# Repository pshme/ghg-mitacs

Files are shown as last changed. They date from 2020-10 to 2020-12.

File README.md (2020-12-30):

# **GHG Sensing Project**

## **Introduction and Overview**

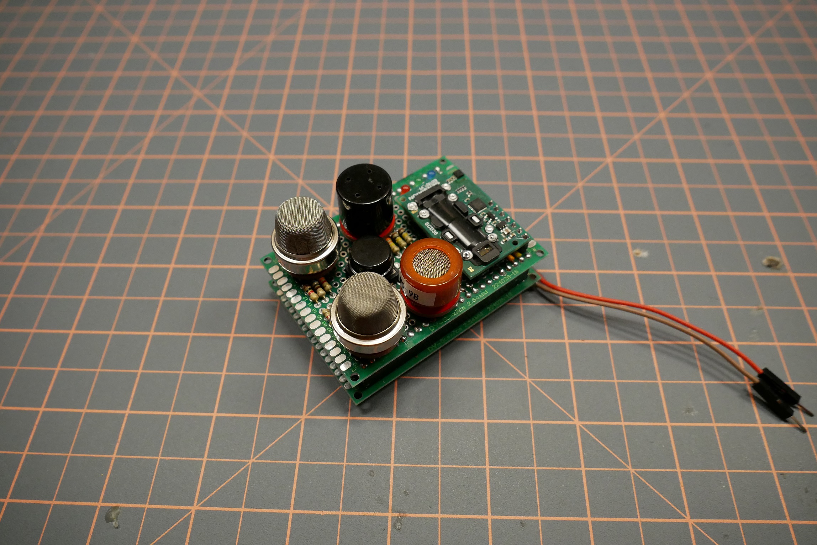
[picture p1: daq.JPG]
DAQ prototype


The purpose of this research project was to find low-cost and low-power sensors and integrate them into a compact DAQ (Data Acquisition) system for use in UAVs (Unmanned Aerial Vehicles). The sensors measure GHGs (Greenhouse Gasses) in the atmosphere along with complementary ambient readings such as temperature, humidity, and pressure.

The prototype DAQ system uses the following components:

* PJRC Teensy 4.1 Arduino-based microcontroller
* Pololu 5V 2.5A Step-Down Regulator (D24V22F5)
* Pololu 3.3V Step-Up/Step-Down Regulator (S7V8F3)
* Sensirion SCD30 CO2, humidity, and temperature sensor
* Winsen MQ-4 CH4 Sensor
* Winsen MQ-9B CO and CH4 Sensor
* Winsen MQ-131 O3 Sensor
* Winsen MQ-137 NH3 Sensor
* SparkFun Barometric Pressure Sensor (MPL115A1)
* SparkFun Gas Sensor Breakout Boards
* Toggle button, LEDs, and resistors.

Each Winsen sensor was individually calibrated to determine the sensor's resistance and also convert the 5V to 3.3V output logic. The Sensirion SCD30 was calibrated by leaving the sensor powered on in an outdoor environment for 1 hour every day. The DAQ records data to the SD card every 2 seconds.

## **Basic Operation**

### **Hardware Controls**

The DAQ has 3 LEDs (one red, one green, and one blue) which represent the state of the system. There are **three** main states and **one** exception state. There is also a button which allows you to either start or end loggint to the SD card. When the DAQ is first powered on, the system is not logging any data and the red LED is *solid*. When the button is pressed, then the system can enter one of the following states: 

* *SOLID* **GREEN**, *FLASHING* **BLUE** - system is logging to SD card every 2 seconds
* *Flashing* **RED, GREEN, BLUE** - error with SD card or SD card not inserted (reboot to resolve)
* *SOLID* **RED, GREEN**, *FLASHING* **BLUE** - O3 sensor not recording data, but other sensors are (exceptions state)

To exit out of one of the four states, the button must be pressed again; however, if there is an error with the SD card or the SD card is not inserted, then you must reboot the DAQ and check that the error is resolved. 

### **Matlab Plotting**

The Arduino code (*main_ghg_code.ino*) has been modified to first display a title for each column in the .txt file. This helps simplify the Matlab import process. Once a test has been logged to the SD card, the **Import Data** function can be used. It is important to make sure that the information is *delimited* by commas and that each column is imported to Workspace as a **column vector**. After importing the section, *daq_import.m* can be ran, and the graphs will be produced. The graphs display the gas concentration, temperature, pressure, or humidity with respect to time which is converted from 2 second intervals to hours:minutes:seconds to make the graph more legible.

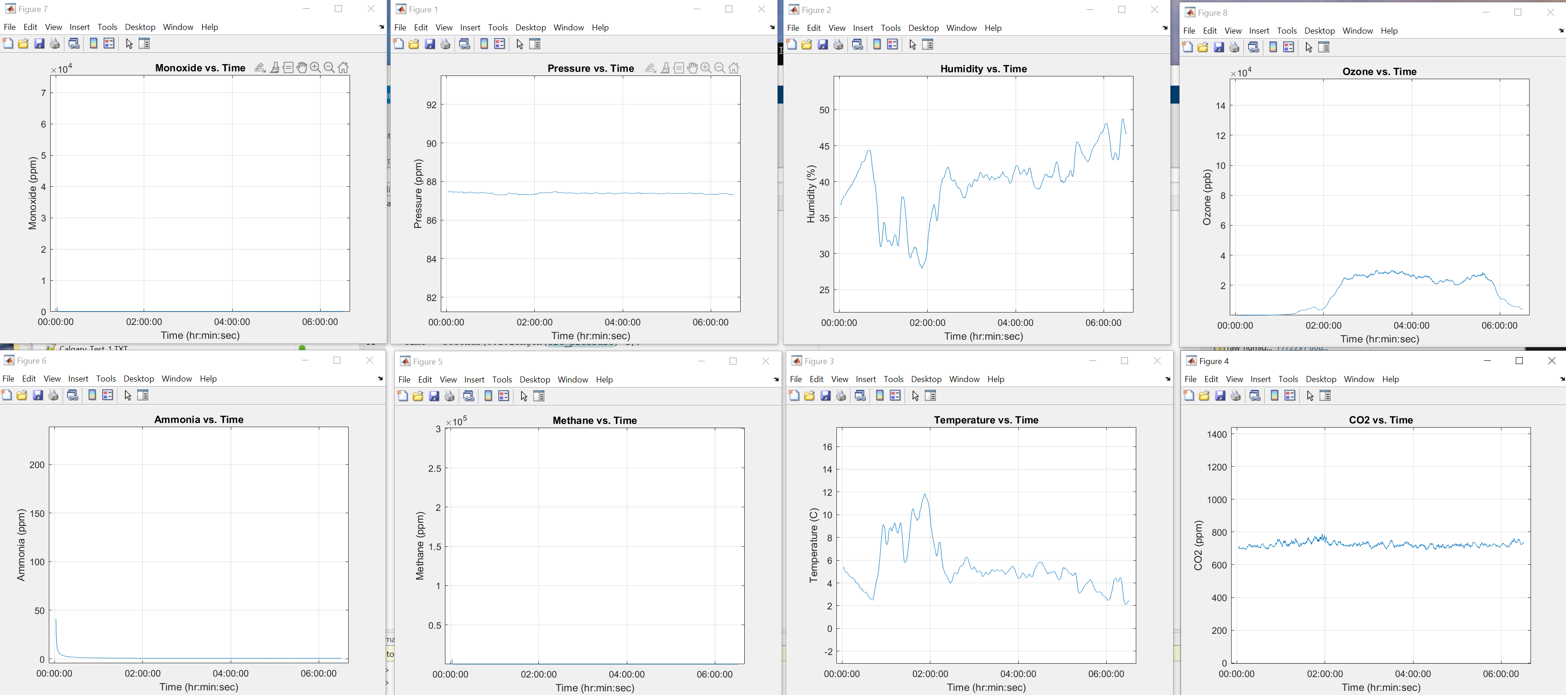
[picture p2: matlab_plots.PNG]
Matlab plots


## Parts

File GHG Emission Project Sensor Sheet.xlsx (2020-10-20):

Manufacturer |  | Gas | Sensor ID | Sensor Type |  | Weight (g) | Dimensions (LxWxHmm) |  | Measurement Accuracy (ppm) |  | Measurement Range (ppm) |  | Measurement Rate (sec/mes.) |  | Voltage Input (VDC) | Peak Current (mA) | Operating Temperature (°C) | Communication Protocol | Price (CAD) | Link
CozIR |  | CO2 | GC-0012 | NDIR |  | 20 | N/A |  | ± 50 ppm ± 3% |  | 0 - 10000 |  | 0.5 |  | 3.3 - 5.5 | 33 | 0 - 50 | UART | $142.70 | https://www.co2meter.com/products/cozir-ambient-10000-ppm-co2-sensor?variant=840094613524
SenseAir |  | CO2 | SE-0018 K30 | NDIR |  | N/A | 51 × 57 × 14 |  | ± 30 ppm ± 3 % |  | 0 - 10000 |  | 2 |  | 5.5 - 14 | 150 | 0 - 50 | UART/I2C | $111.28 | https://www.co2meter.com/products/k-30-co2-sensor-module
SenseAir |  | CO2 | SE-0119 S8 | NDIR |  | 8 | 32.7 × 19.7 × 8 |  | ± 70ppm ± 3% |  | 0 - 10000 |  | 2 |  | 4.5 - 5.25 | 300 | 0 - 50 | UART/Modbus | $111.28 | https://www.co2meter.com/products/s8-miniature-co2-sensor-1
SenseAir |  | CO2 | SE-0038 LP8 | NDIR |  | 8 | 32.7 × 19.7 × 8 |  | ± 50ppm ± 3% |  | 0 - 10000 |  | >15 |  | 2.9 - 5.5 | 125 | 0 - 50 | UART | $155.79 | https://www.co2meter.com/products/lp8-miniature-co2-sensor
CozIR |  | CO2 | GC-0027 | NDIR |  | 5 | 31 x 19.5 x 8 |  | ± 50ppm ± 3% |  | 0 - 5000 |  | <30 |  | 3.25 - 5.5 | 33 | 0 - 50 | UART | $142.70 | https://www.co2meter.com/products/cozir-lp-ambient-air-co2-sensor?variant=40754444884
SprintIR |  | CO2 | GC-0028 | NDIR |  | 16 | 25 x 40 x 31 |  | ± 70ppm ± 5% |  | 0 - 50000 |  | 2 |  | 3.25 - 5.5 | 33 | 0 - 50 | UART | $325.98 | https://www.co2meter.com/products/sprintir6s-5-co2-smart-sensor
SenseAir |  | CO2 | SE-11 | NDIR |  | 4.9 | 33 x 19.8 x 11.9 |  | ± 30ppm ± 3% |  | 400 - 10000 |  | 2 |  | 3.05 - 5.5 | 125 | 0 - 50 | UART/I2C | $82.46 | https://www.digikey.ca/en/products/detail/senseair-north-america-inc/006-0-0002/10416535
Sensirion |  | CO2 | SCD30 | NDIR |  | 3.4 | 35 x 23 x 7.00 |  | ± 30ppm ± 3% |  | 400 - 10000 |  | 2 |  | 3.3 - 5.5 | 75 | 0 - 50 | UART/I2C | $81.78 | https://www.digikey.ca/en/products/detail/sensirion-ag/SCD30/8445334
Fiargo |  | CO2 | FG-010 | NDIR |  | 3 | 32 x 17 x 7.4 |  | ± 50ppm ± 3% |  | 300 - 5000 |  | 2 |  | 4.75 - 5.25 | 60 | 0 - 50 | UART/I2C/PWM | $155.79 | https://www.co2meter.com/collections/0-1-co2/products/figaro-5000ppm-co2-sensor
NCD |  | CH4 | MQ-4 | MOS |  | N/A | N/A |  | N/A |  | 200 - 10000 |  | N/A |  | 5 | N/A | -10 - 50 | I2C | $39.32 | https://store.ncd.io/product/mq-4-methane-natural-gas-sensor-adc121c-12-bit-adc-i2c-mini-module/
NCD |  | CO | MQ-7 | MOS |  | N/A | N/A |  | N/A |  | 20 - 2000 |  | N/A |  | 5 | N/A | -20 - 50 | I2C | $39.32 | https://store.ncd.io/product/mq-7-carbon-monoxide-gas-sensor-adc121c-12-bit-adc-i2c-mini-module/
DF Robot |  | O3 | SEN0321 | EC |  | 22 | 37 x 27 |  | N/A |  | 0 - 10 |  | <90 |  | 3.3 - 5 | N/A | -20 - 50 | I2C | $70.56 | https://www.mouser.ca/ProductDetail/DFRobot/SEN0321?qs=GedFDFLaBXFKYEA7aR%2FFOA%3D%3D
NCD |  | O3 | MQ131 | MOS |  | N/A | N/A |  | N/A |  | 10 - 1000 |  | N/A |  | 5 | N/A | N/A | I2C | $56.29 | https://store.ncd.io/product/mq131-ozone-gas-sensor-adc121c-12-bit-adc-i%c2%b2c-mini-module/
Euro Gasman |  | All | 4 Series MS | EC |  | N/A | 23 x 22 x 24.5 |  | N/A |  | N/A |  | N/A |  | 3.3 - 5 | N/A | N/A | I2C | N/A | https://euro-gasman.com/product/4-8v-digital-i2cbus-transmitter/
SpecSensors |  | CO | DGS-CO 968-034 | EC |  | 20 | 44.5 x 20.8 x 8.9 |  | ± 15% |  | 0 - 1000 |  | 5 |  | 2.6 - 3.6 | 4 | -30 - 50 | UART | 113.59 | https://www.digikey.ca/en/products/detail/spec-sensors-llc/968-034/6676880
SpecSensors |  | O3 | DGS-O3968-042 | EC |  | 20 | 44.5 x 20.8 x 8.9 |  | ± 15% |  | 0 - 5 |  | 1 |  | 3.0 - 3.6 | 4.3 | -30 - 50 | UART | 113.59 | https://www.digikey.ca/en/products/detail/spec-sensors-llc/968-042/7689227
SpecSensors |  | NO2 | DGS-NO2968-043 | EC |  | 20 | 44.5 x 20.8 x 8.9 |  | ± 15% |  | 0 - 5 |  | 1 |  | 3.0 - 3.6 | 4.3 | -30 - 50 | UART | 113.59 | https://www.digikey.ca/en/products/detail/spec-sensors-llc/968-043/7689228
Winsen |  | CO | MQ-7 | MOS |  | 10 | 30 x 20 x 20 |  | ± ~30% |  | 10 - 1000 |  | 1 |  | 5 | 250 | -20 - 50 | Analog | $7.99 | https://x2robotics.ca/mq-7-carbon-monoxide-gas-sensor?search=MQ
Winsen |  | CH4 | MQ-4 | MOS |  | 10 | 30 x 20 x 20 |  | ± ~30% |  | 300 - 10000 |  | 1 |  | 5 | 250 | -20 - 50 | Analog | $5.99 | https://x2robotics.ca/mq-4-methane-gas-sensor?search=MQ
Winsen |  | H2 | MQ-8 | MOS |  | 10 | 30 x 20 x 20 |  | ± ~30% |  | 100 - 1000 |  | 1 |  | 5 | 250 | -20 - 50 | Analog | $5.99 | https://x2robotics.ca/mq-8-hydrogen-gas-sensor?search=MQ
Mikroe |  | CO | MIKROE-3196 | EC |  | 20 | 57.2 x 25x4 x 10 |  | ± 15% |  | 0 - 1000 |  | 5 |  | 3.3 - 5 | ~50 | -30 - 50 | Analog/I2C | $68.99 | https://www.mikroe.com/co-2-click
Mikroe |  | NH3 | MIKROE-4151 | MOS |  | 20 | 57.15 x 25.4 x 10 |  | ± ~30% |  | 5 - 200 |  | 1 |  | 3.3 - 5 | 250 | -30 - 50 | Analog/SPI | $68.99 | https://www.mikroe.com/ammonia-click
Mikroe |  | O3 | MIKROE-2767 | MOS |  | 20 | 57.2 x 25x4 x 10 |  | ± ~30% |  | 10 - 1000 |  | 1 |  | 3.3 - 5 | 250 | -20 - 50 | Analog/SPI | $48.85 | https://www.mikroe.com/ozone-2-click
Mikroe |  | NO2 | MIKROE-3098 | MOS |  | 20 | 57.2 x 25x4 x 10 |  | ± 15% |  | 0 - 20 |  | 1 |  | 3.3 - 5 | ~50 | -30 - 50 | Analog/I2C | $68.99 | https://www.mikroe.com/no2-click
 | Agricultural Emissions |  |  | Abreviation |  |  | Manufacturer | Sensor Type |  | Protocol | Price (CAD) | Link |  | Total Current (mA)
 | CO2 |  | 400ppm+ | MOS | Semiconductor |  | Sparkfun | Accelerometer |  | I2C | $13.14 | https://www.sparkfun.com/products/12756 |  | 875
 | CH4 |  | 1.8 - 2ppm | EC | Electrochemical |  | Sparkfun | Temperature |  | I2C | $5.61 | https://www.sparkfun.com/products/13314 | .1 deg C
 | CO |  | 0 - 2ppm | CAT | Catalytic |  | Sparkfun | Alt/Pressure |  | I2C | $19.74 | https://www.sparkfun.com/products/11084 | good resolution
 | NH3 |  | 0 - 0.2ppb | NDIR | Infrared |  | Sparkfun | Humidity |  | I2C | $13.14 | https://www.sparkfun.com/products/16467 | 1%
 | NO2 |  | 0 - 160ppb
 | O3 |  | 0-3ppm
 | H2
 | NH4
 | NO |  |  |  |  |  | Typical Range table
 | N2O |  |  |  |  |  | environment |  |  | https://www.figarosensor.com/product/entry/tgs2600.html#ti
 |  |  |  |  |  |  | agricultural emmison
 |  |  |  |  |  |  | inlcude Teensy
 |  |  |  |  |  |  | breadboard
 |  |  |  |  |  |  | perfboard
 |  |  |  |  |  |  | solder
 |  |  |  |  |  |  | tools

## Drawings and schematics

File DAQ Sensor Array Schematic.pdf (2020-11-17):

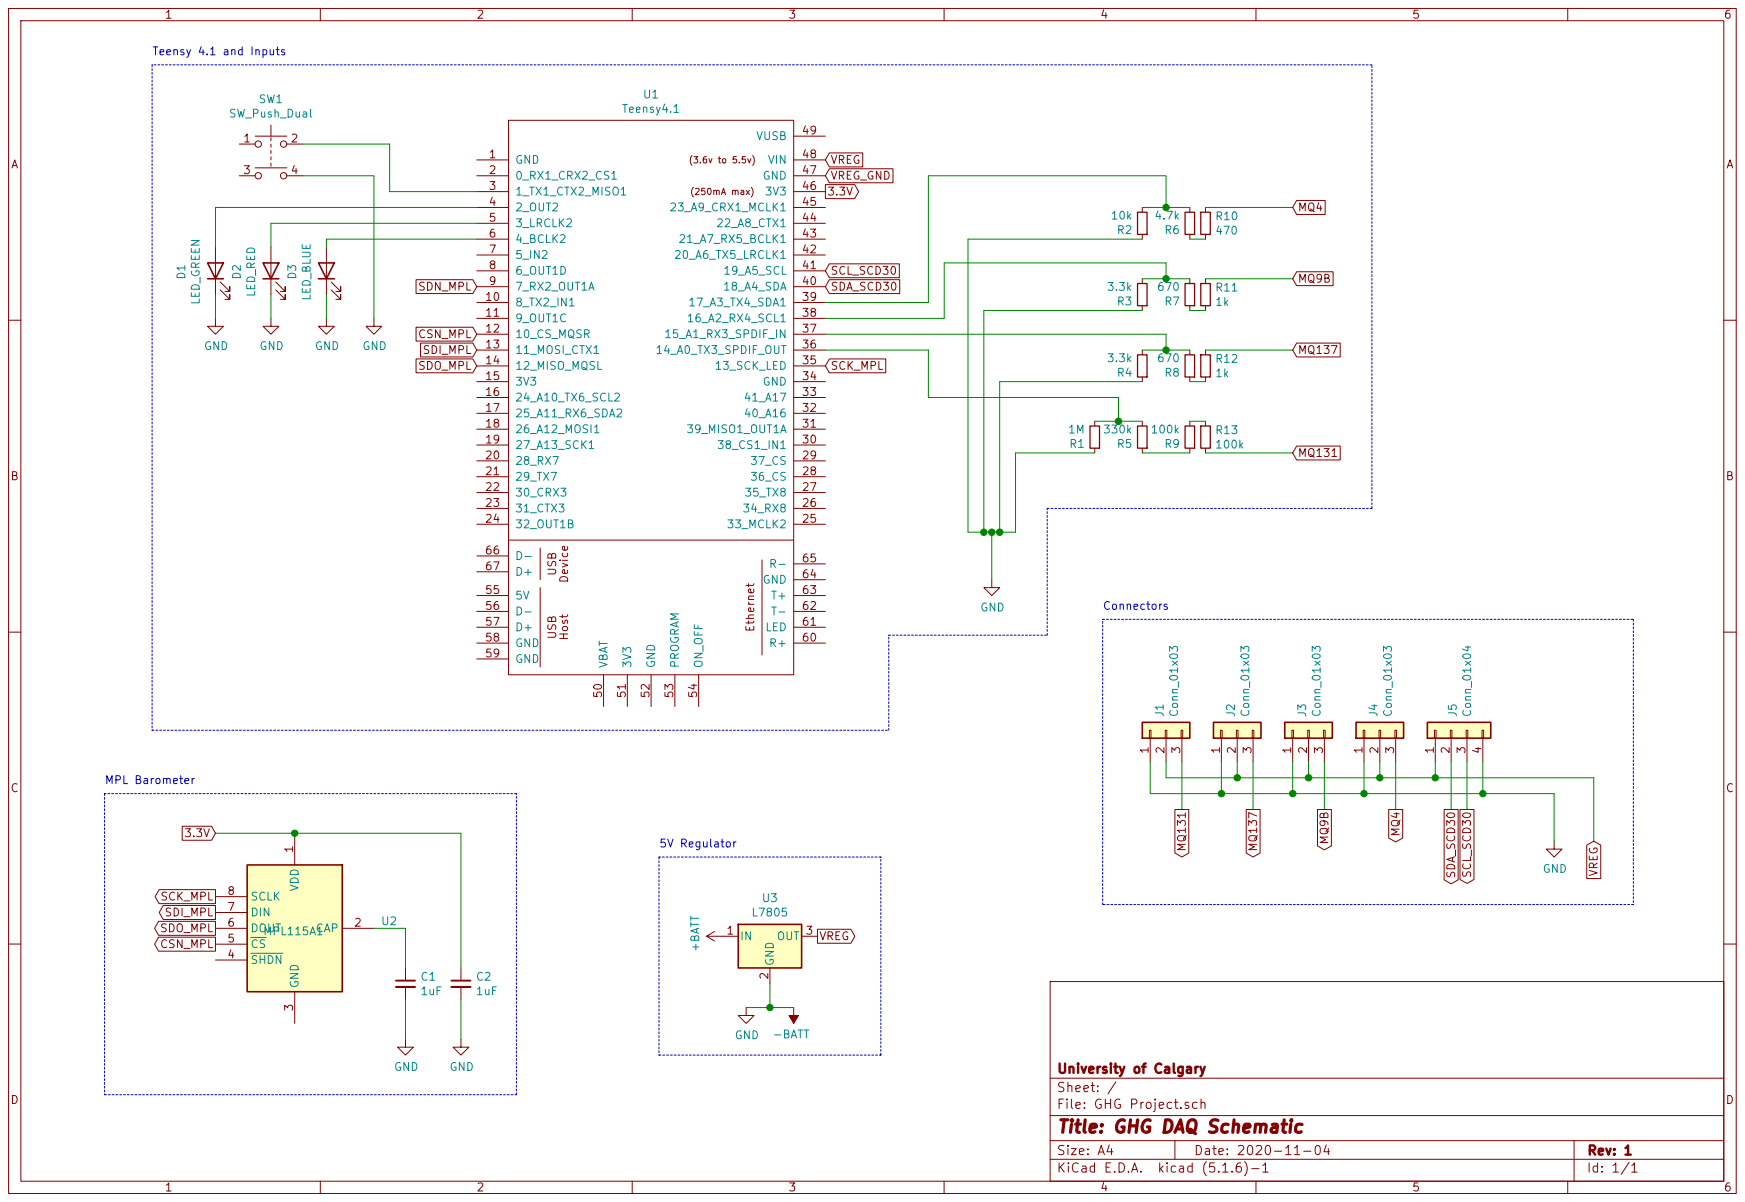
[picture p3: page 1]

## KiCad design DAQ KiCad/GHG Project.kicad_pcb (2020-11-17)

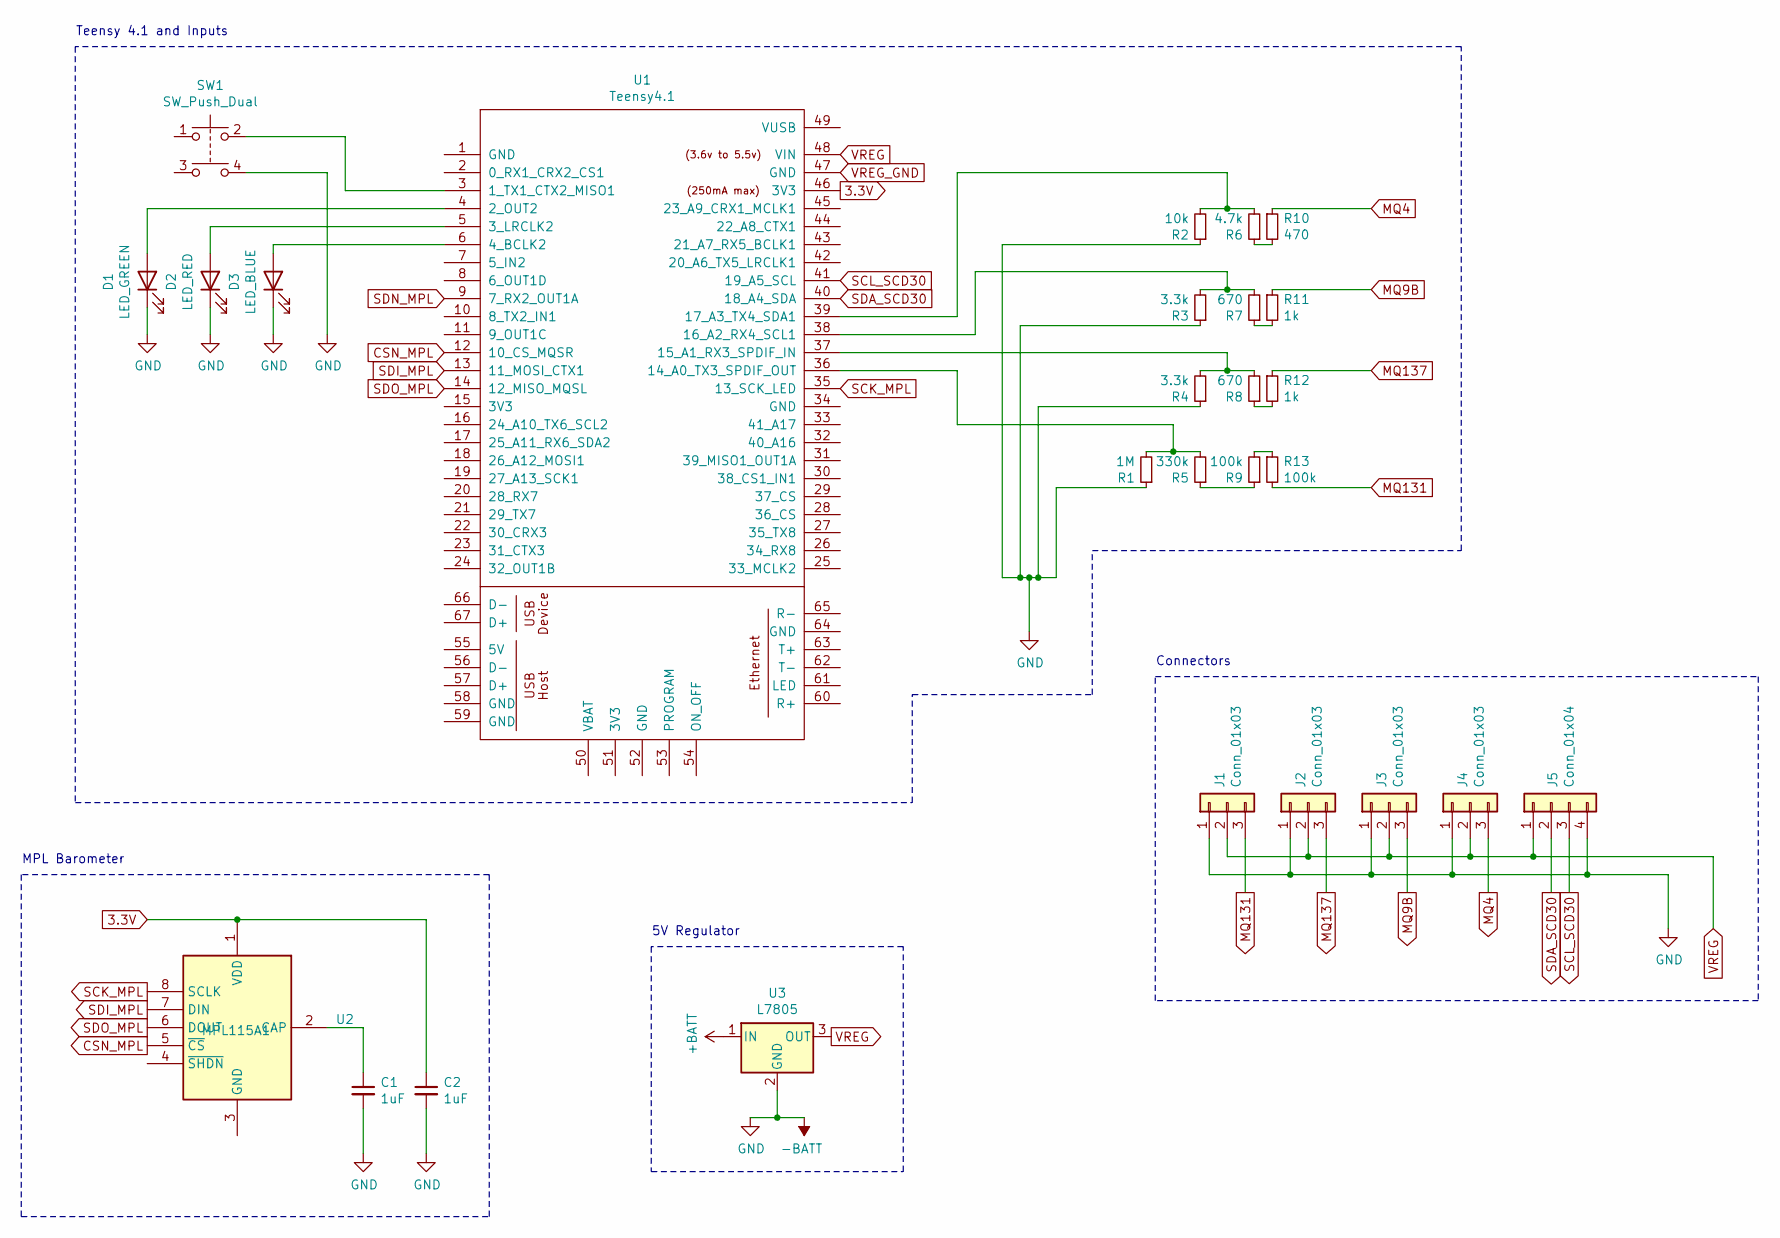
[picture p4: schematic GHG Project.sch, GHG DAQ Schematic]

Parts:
C1, C2: 1uF; C_0402_1005Metric
D1: LED_GREEN; LED_0603_1608Metric
D2: LED_RED; LED_0603_1608Metric
D3: LED_BLUE; LED_0603_1608Metric
J1, J2, J3, J4: Conn_01x03; JST_EH_B3B-EH-A_1x03_P2.50mm_Vertical
J5: Conn_01x04; JST_EH_B4B-EH-A_1x04_P2.50mm_Vertical
R1: 1M; R_0603_1608Metric
R2: 10k; R_0603_1608Metric
R3, R4: 3.3k; R_0603_1608Metric
R5: 330k; R_0603_1608Metric
R6: 4.7k; R_0603_1608Metric
R7, R8: 670; R_0603_1608Metric
R9, R13: 100k; R_0603_1608Metric
R10: 470; R_0603_1608Metric
R11, R12: 1k; R_0603_1608Metric
SW1: SW_Push_Dual; SW_Push_1P1T_NO_CK_KMR2
U1: Teensy4.1; Teensy41
U2: MPL115A1; NXP_LGA-8_3x5mm_P1.25mm_H1.2mm
U3: L7805

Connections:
3.3V: C2.1, U1.46 (3V3), U2.1 (VDD)
-BATT: C1.2, C2.2, D1.1 (K), D2.1 (K), D3.1 (K), J1.1, J2.1, J3.1, J4.1, J5.4, R1.1, R2.1, R3.1, R4.1, SW1.4, U3.2 (GND)
CSN_MPL: U1.12 (10_CS_MQSR), U2.5 (~CS)
MQ4: J4.3, R10.1
MQ9B: J3.3, R11.1
MQ131: J1.3, R13.2
MQ137: J2.3, R12.1
unnamed: C1.1, U2.2 (CAP)
unnamed: D1.2 (A), U1.4 (2_OUT2)
unnamed: D2.2 (A), U1.5 (3_LRCLK2)
unnamed: D3.2 (A), U1.6 (4_BCLK2)
unnamed: R1.2, R5.2, U1.36 (14_A0_TX3_SPDIF_OUT)
unnamed: R2.2, R6.2, U1.39 (17_A3_TX4_SDA1)
unnamed: R3.2, R7.2, U1.38 (16_A2_RX4_SCL1)
unnamed: R4.2, R8.2, U1.37 (15_A1_RX3_SPDIF_IN)
unnamed: R5.1, R9.1
unnamed: R6.1, R10.2
unnamed: R7.1, R11.2
unnamed: R8.1, R12.2
unnamed: R9.2, R13.1
unnamed: SW1.2, U1.3 (1_TX1_CTX2_MISO1)
SCK_MPL: U1.35 (13_SCK_LED), U2.8 (SCLK)
SCL_SCD30: J5.3, U1.41 (19_A5_SCL)
SDA_SCD30: J5.2, U1.40 (18_A4_SDA)
SDI_MPL: U1.13 (11_MOSI_CTX1), U2.7 (DIN)
SDN_MPL: U1.9 (7_RX2_OUT1A)
SDO_MPL: U1.14 (12_MISO_MQSL), U2.6 (DOUT)
VREG: J1.2, J2.2, J3.2, J4.2, J5.1, U1.48 (VIN), U3.3 (OUT)
VREG_GND: U1.47 (GND)

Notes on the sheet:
Connectors
5V Regulator
MPL Barometer
Teensy 4.1 and Inputs

Board: 2 copper layers, 26 parts (0 on the bottom side), 27 nets, no tracks yet.

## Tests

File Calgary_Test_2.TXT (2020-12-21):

raw_pressure,raw_co2,raw_temperature,raw_humidity,raw_methane,raw_ammonia,raw_monoxide,raw_ozone,
87.35,532,6.8,36.2,301306.14,138.57,46169.47,15.58,
87.49,585,6.6,36.6,174460.48,182.25,75643.02,9.92,
87.53,654,6.6,36.4,196801.70,229.89,34854.55,8.95,
87.49,688,6.7,35.9,56200.17,233.95,15580.18,10.00,
87.49,688,6.6,35.4,38301.82,212.75,7669.15,8.90,
87.45,687,6.4,35.1,12509.40,213.36,2871.27,7.82,
87.40,698,6.3,34.8,6735.55,201.70,1386.32,9.25,
87.40,694,6.3,34.6,3703.15,163.06,762.62,10.93,
87.54,694,6.3,34.6,2160.73,159.71,321.02,8.85,
87.26,699,6.2,34.6,1334.23,142.43,205.22,8.83,
87.27,689,6.0,34.4,910.25,120.90,178.45,8.83,
87.36,688,5.9,34.4,648.86,121.19,134.75,9.30,
87.31,678,5.9,34.3,554.30,105.03,116.13,10.65,
87.36,664,6.0,34.5,451.98,98.30,101.14,9.28,
87.50,660,6.0,35.0,410.88,91.89,90.37,8.76,
87.36,659,6.0,35.6,344.69,85.62,62.06,8.34,
87.64,672,6.0,36.1,300.66,85.43,51.58,8.90,
87.31,678,6.0,36.4,258.74,77.66,45.36,8.20,
87.50,676,6.0,36.7,210.95,70.00,33.47,8.36,
87.46,669,6.0,36.6,209.23,65.49,26.50,9.67,
87.50,669,6.0,36.6,197.63,61.32,25.13,9.57,
87.24,670,5.8,36.0,179.06,62.46,20.88,9.05,
87.14,677,5.9,35.7,165.00,59.59,23.25,9.92,
87.60,674,5.8,35.6,149.72,57.00,17.22,8.81,
87.36,672,5.7,35.4,143.22,54.76,17.51,9.95,
87.55,664,5.7,35.3,104.14,53.57,9.39,8.85,
87.41,671,5.7,35.4,96.85,49.98,13.26,9.25,
87.46,679,5.7,35.4,100.43,47.68,12.64,10.09,
87.36,693,5.8,35.3,89.36,47.49,11.63,9.67,
87.27,706,5.7,35.5,91.50,45.59,11.73,11.78,
87.41,701,5.7,35.8,83.87,45.77,8.27,8.52,
87.23,701,5.7,35.8,81.25,44.11,8.38,9.67,
87.41,719,5.8,35.9,78.32,40.38,8.08,9.98,
87.23,727,5.9,36.0,73.71,38.58,7.51,9.87,
87.46,703,5.8,35.8,71.39,39.62,6.22,9.81,
87.41,687,5.8,35.7,70.14,37.15,6.05,9.81,
87.27,706,5.7,35.6,67.91,34.59,5.91,10.18,
87.60,760,5.6,35.5,66.18,35.64,5.14,9.98,
87.46,855,5.7,35.4,65.76,33.95,5.31,10.18,
87.51,844,5.7,35.5,65.01,32.40,5.16,10.15,
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

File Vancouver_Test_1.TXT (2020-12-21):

raw_pressure,raw_co2,raw_temperature,raw_humidity,raw_methane,raw_ammonia,raw_monoxide,raw_ozone,
102.04,0,24.2,39.6,36025.90,41.64,1.78,257.01,
102.62,1432,24.2,38.7,49265.60,130.62,3277.73,18.92,
102.33,1424,19.9,45.9,35.33,6.37,1.01,10.62,
101.99,1276,19.4,45.6,35.45,7.67,0.90,10.53,
102.04,1009,19.3,44.9,31.47,7.60,0.86,10.53,
102.23,903,19.3,46.4,31.88,6.86,0.81,10.86,
102.09,752,19.3,48.8,32.23,5.99,0.78,10.80,
102.23,933,19.2,47.6,31.07,5.82,0.64,10.74,
102.09,835,19.4,45.6,31.47,5.55,0.63,10.83,
102.04,749,19.5,44.2,31.82,5.30,0.66,11.15,
102.23,705,19.5,43.4,30.34,5.37,0.59,10.89,
102.04,783,19.5,42.8,30.73,5.11,0.62,11.18,
101.94,777,19.5,42.4,30.45,5.04,0.58,11.02,
101.99,777,19.5,42.4,30.06,5.14,0.52,11.15,
102.57,738,19.5,42.0,30.67,4.93,0.57,11.28,
101.94,733,19.5,41.6,29.39,4.95,0.51,11.24,
102.04,750,19.4,41.6,30.11,4.93,0.50,11.31,
102.04,772,19.4,41.7,29.95,4.81,0.50,11.24,
102.04,735,19.2,42.1,29.39,4.74,0.54,11.57,
102.23,688,19.1,42.2,30.06,4.66,0.54,11.57,
102.04,714,19.0,42.4,30.73,4.66,0.55,11.64,
102.14,725,19.0,42.7,28.42,4.56,0.46,11.47,
101.89,715,18.9,43.0,29.18,4.50,0.45,11.61,
102.14,713,18.9,43.0,29.29,4.30,0.48,11.74,
102.09,727,18.9,43.0,29.45,4.37,0.50,11.99,
101.94,727,18.9,43.0,29.56,4.31,0.41,11.81,
102.38,735,18.9,43.1,29.18,4.11,0.45,12.16,
101.94,720,18.9,43.3,28.91,4.03,0.42,12.27,
101.99,727,18.8,43.3,27.89,4.07,0.42,12.31,
101.94,710,18.8,43.2,28.91,3.96,0.42,12.27,
102.09,737,18.7,43.2,28.58,3.92,0.41,12.27,
101.99,747,18.7,43.3,28.37,4.00,0.36,12.34,
102.13,736,18.6,43.5,28.00,3.95,0.37,12.31,
101.94,703,18.7,43.3,27.95,3.70,0.38,12.75,
102.18,703,18.6,43.5,27.42,3.69,0.38,12.56,
102.28,700,18.6,43.2,26.91,3.76,0.36,12.68,
101.84,716,18.6,43.1,27.58,3.58,0.37,12.90,
102.33,716,18.6,43.1,26.91,3.58,0.35,12.71,
102.13,715,18.4,43.2,26.35,3.67,0.33,12.79,
101.94,705,18.3,43.1,26.96,3.46,0.36,13.06,
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

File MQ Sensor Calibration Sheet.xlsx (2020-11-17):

MQ4 |  |  |  |  |  | MQ9B |  | MQ137 |  | MQ131 |  | MQ7
ppm | Rs/Ro |  |  |  |  | ppm | Rs/Ro | ppm | Rs/Ro | ppb | Rs/Ro | ppm | Rs/Ro
300 | 0.25 |  |  |  |  | 10 | 0.25 | 1 | 0.57 | 10 | 1.1 | 400 | 0.16
400 | 0.195 |  |  |  |  | 20 | 0.17 | 2 | 0.49 | 20 | 1.55 | 500 | 0.155
500 | 0.165 |  |  |  |  | 30 | 0.135 | 3 | 0.445 | 30 | 1.65 | 600 | 0.147
600 | 0.15 |  |  |  |  | 40 | 0.12 | 4 | 0.405 | 40 | 1.8 | 700 | 0.138
700 | 0.143 |  |  |  |  | 50 | 0.095 | 5 | 0.385 | 50 | 2 | 800 | 0.13
800 | 0.135 |  |  |  |  | 60 | 0.085 | 6 | 0.36 | 60 | 2.1 | 900 | 0.125
900 | 0.12 |  |  |  |  | 70 | 0.08 | 7 | 0.35 | 70 | 2.2 | 1000 | 0.105
1000 | 0.1 |  |  |  |  | 80 | 0.075 | 8 | 0.34 | 80 | 2.5 | 2000 | 0.085
2000 | 0.068 |  |  |  |  | 90 | 0.07 | 9 | 0.33 | 90 | 2.55 | 3000 | 0.074
3000 | 0.055 |  |  |  |  | 100 | 0.065 | 10 | 0.32 | 100 | 2.6 | 4000 | 0.066
4000 | 0.047 |  |  |  |  | 200 | 0.045 | 20 | 0.26 | 200 | 4 | 5000 | 0.0605
5000 | 0.041 |  |  |  |  | 300 | 0.035 | 30 | 0.245 | 300 | 5 | 6000 | 0.056
6000 | 0.036 |  |  |  |  | 400 | 0.03 | 40 | 0.22 | 400 | 5.5 | 7000 | 0.0535
7000 | 0.034 |  |  |  |  | 500 | 0.028 | 50 | 0.21 | 500 | 6 | 8000 | 0.0505
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

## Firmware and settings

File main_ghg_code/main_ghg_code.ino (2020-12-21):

/*
MPL115A1
 SDN       : pin 7
 CSN       : pin 10
 SDI/MOSI  : pin 11
 SDO/MISO  : pin 12
 SCK       : pin 13
*/

#include <SPI.h>
#include <SD.h>
#include <Wire.h>
#include <ezButton.h>
#include "SparkFun_SCD30_Arduino_Library.h"

SCD30 airSensor;

//***************************************************************
//MPL115A1 Arduino Code by huinink
//https://forum.sparkfun.com/viewtopic.php?t=23965
#define PRESH  0x80
#define PRESL 0x82
#define TEMPH 0x84
#define TEMPL 0x86

#define A0MSB 0x88
#define A0LSB 0x8A
#define B1MSB 0x8C
#define B1LSB 0x8E
#define B2MSB 0x90
#define B2LSB 0x92
#define C12MSB  0x94
#define C12LSB  0x96

#define CONVERT 0x24  

#define chipSelectPin 10
#define shutDown 9
//***************************************************************

#define buttonPin  7
#define ledPinGreen  2
#define ledPinRed 4
#define ledPinBlue 0

#define mq9bpin 6
#define mq137pin 8
#define mq4pin 9
#define mq131pin 7

//               n--m--sensorRes--totalRes--terminalRes   
const float mq4[] = {1/0.621,8.0933,35.0,15.17,10.0};
const float mq137[] = {1/0.0265,0.5845,38.9,4.97,3.3};
const float mq9b[] = {1/0.542,0.8239,27.0,4.97,3.3};
const float mq131[] = {1/0.4493,0.3579,4195,1530,1000};

const int chipSelect = BUILTIN_SDCARD;

ezButton button(buttonPin);

int ledState = LOW;
int lastButtonState;
int currentButtonState;

float A0_;
float B1_;
float B2_;
float C12_;

unsigned long previousTime = 0;

void setup() 
{ 
  Serial.begin(115200);
  SPI.begin(); 
  Wire.begin();
  SD.begin(chipSelect);
  airSensor.begin();

  pinMode(mq9bpin, INPUT);
  pinMode(mq137pin, INPUT);
  pinMode(mq4pin, INPUT);
  pinMode(mq131pin, INPUT);

  analogReadResolution(12);

  pinMode(chipSelect, OUTPUT);
  
  //initializing CS and SDN pins
  pinMode(shutDown, OUTPUT);
  digitalWrite(shutDown, HIGH);
  pinMode(chipSelectPin, OUTPUT);
  digitalWrite(chipSelectPin, HIGH);

  //initializing LED pins
  pinMode(buttonPin, INPUT_PULLUP);
  pinMode(ledPinGreen, OUTPUT);
  pinMode(ledPinRed, OUTPUT);
  pinMode(ledPinBlue, OUTPUT);
  digitalWrite(ledPinRed, HIGH);

  button.setDebounceTime(50);

  currentButtonState = LOW;

  airSensor.setMeasurementInterval(2); //in seconds
  airSensor.setAltitudeCompensation(1045); //in metres
  airSensor.setAmbientPressure(900); //in mBar
  airSensor.setTemperatureOffset(2);

//***************************************************************
//MPL115A1 Arduino Code by huinink
//https://forum.sparkfun.com/viewtopic.php?t=23965
  unsigned int A0H = readRegister(A0MSB);
  unsigned int A0L = readRegister(A0LSB);
         A0_ = (A0H << 5) + (A0L >> 3) + (A0L & 0x07) / 8.0;
  
  unsigned int B1H = readRegister(B1MSB);
  unsigned int B1L = readRegister(B1LSB);
          B1_ = ( ( ( (B1H & 0x1F) * 0x100)+B1L) / 8192.0) - 3 ;
  
  unsigned int B2H = readRegister(B2MSB);
  unsigned int B2L = readRegister(B2LSB);
          B2_ = ( ( ( (B2H - 0x80) << 8) + B2L) / 16384.0 ) - 2 ;
  
  unsigned int C12H = readRegister(C12MSB);
  unsigned int C12L = readRegister(C12LSB);
          C12_ = ( ( ( C12H * 0x100 ) + C12L) / 16777216.0 )  ;
//***************************************************************

File dataFile = SD.open("BARO.txt", FILE_WRITE);
dataFile.println("raw_pressure,raw_co2,raw_temperature,raw_humidity,raw_methane,raw_ammonia,raw_monoxide,raw_ozone");
dataFile.close();
}

void loop() 
{
  button.loop();
  
  lastButtonState = currentButtonState;
  currentButtonState = digitalRead(buttonPin);

  unsigned long currentTime = millis(); //lasts up to 50 days until overflow occurs 

  if (button.isPressed())
  {
    ledState = !ledState;
    digitalWrite(ledPinGreen, ledState);
    digitalWrite(ledPinRed, !ledState);
  }

  if ((currentTime - previousTime) == 2000 || (currentTime - previousTime) > 2000)
  {
    if (ledState)
    {
       File dataFile = SD.open("BARO.txt", FILE_WRITE);

       if ((int)ozone() == 0)
       {
          digitalWrite(ledPinRed, HIGH);
       }
  
       if (dataFile)
       {
            //Print to serial display
            digitalWrite(ledPinBlue,HIGH);
            Serial.print(baroPressure());
            Serial.print(",");
            Serial.print(airSensor.getCO2(),1);
            Serial.print(",");
            Serial.print(airSensor.getTemperature(),1);
            Serial.print(",");
            Serial.print(airSensor.getHumidity(),1);
            Serial.print(",");
            Serial.print(methane());
            Serial.print(",");
            Serial.print(monoxide());
            Serial.print(",");
            Serial.print(ammonia());
            Serial.print(",");
            Serial.print(ozone());
            Serial.println(",");
  
            //Write to SD Card
            dataFile.print(baroPressure());
            dataFile.print(",");
            dataFile.print(airSensor.getCO2(),1);
            dataFile.print(",");
            dataFile.print(airSensor.getTemperature(),1);
            dataFile.print(",");
            dataFile.print(airSensor.getHumidity(),1);
            dataFile.print(",");
            dataFile.print(methane());
            dataFile.print(",");
            dataFile.print(monoxide());
            dataFile.print(",");
            dataFile.print(ammonia());
            dataFile.print(",");
            dataFile.println(ozone());
            dataFile.close();
            digitalWrite(ledPinBlue,LOW);
           }
  
           else
           {
              digitalWrite(ledPinGreen,LOW);
              
              while(!dataFile)
              {
                digitalWrite(ledPinRed,HIGH);
                digitalWrite(ledPinGreen,HIGH);
                digitalWrite(ledPinBlue,HIGH);
                delay(200);
                digitalWrite(ledPinRed,LOW);
                digitalWrite(ledPinGreen,LOW);
                digitalWrite(ledPinBlue,LOW);
                delay(200);
              }
           }        
        }
        previousTime = currentTime;
    }
}  

double methane()
{
  const float n = 1/0.621; //power
  const float m = 8.0933; //numerator
  float sensor_analog = analogRead(mq4pin); //reading analog value from pin 0
  float sensor_voltage = sensor_analog*(3.3/4095.0); //ADC conversion
  float rs_target_gas = (5.0*10/sensor_voltage)-15.17; //calculation of resistance using voltage divider
  float ratio = rs_target_gas/35.0; //ratio rs/r0

  double ppm = pow((m/ratio),n);
  return ppm;
}

double monoxide()
{
  const float n = 1/0.542; //power
  const float m = 0.8239; //numerator
  
  float sensor_analog = analogRead(mq9bpin); //reading analog value from pin 0
  float sensor_voltage = sensor_analog*(3.3/4095.0); //ADC conversion
  float rs_target_gas = (5.0*3.3/sensor_voltage)-4.97; //calculation of resistance using voltage divider
  float ratio = rs_target_gas/27.0; //ratio rs/r0

  double ppm = pow((m/ratio),n);
  return ppm;
  
}

double ammonia()
{
  const float n = 1/0.265; //power
  const float m = 0.5845; //numerator
  
  float sensor_analog = analogRead(mq137pin); //reading analog value from pin 0
  float sensor_voltage = sensor_analog*(3.3/4095.0); //ADC conversion
  float rs_target_gas = (5.0*3.3/sensor_voltage)-4.97; //calculation of resistance using voltage divider
  float ratio = rs_target_gas/38.9; //ratio rs/r0

  double ppm = pow((m/ratio),n);
  return ppm;
}

double ozone()
{
  const float n = 1/0.4493; //power
  const float m = 0.3579; //denominator
  
  float sensor_analog = analogRead(mq131pin); //reading analog value from pin 0
  float sensor_voltage = sensor_analog*(3.3/4095.0); //ADC conversion
  float rs_target_gas = (5.0*1000/sensor_voltage)-1530; //calculation of resistance using voltage divider
  float ratio = rs_target_gas/4195; //ratio rs/r0

  double ppb = pow((ratio/m),n);
  return ppb;
}

//***************************************************************
//MPL115A1 Arduino Code by huinink
//https://forum.sparkfun.com/viewtopic.php?t=23965
unsigned int readRegister(byte thisRegister ) 
{
  unsigned int result = 0;   // result to return
  digitalWrite(chipSelectPin, LOW);
    delay(10);
    SPI.transfer(thisRegister);
    result = SPI.transfer(0x00);
  digitalWrite(chipSelectPin, HIGH);
  return(result);
}

float baroPressure()
{
  digitalWrite(chipSelectPin, LOW);
  delay(3);
    SPI.transfer(0x24);
    SPI.transfer(0x00);
    digitalWrite(chipSelectPin, HIGH);
    delay(3);
  digitalWrite(chipSelectPin, LOW);
    SPI.transfer(PRESH);
    unsigned int presH = SPI.transfer(0x00);
        delay(3);
    SPI.transfer(PRESL);
    unsigned int presL = SPI.transfer(0x00);
        delay(3);
    SPI.transfer(TEMPH);
    unsigned int tempH = SPI.transfer(0x00);
        delay(3);
    SPI.transfer(TEMPL);
    unsigned int tempL = SPI.transfer(0x00);
        delay(3);
    SPI.transfer(0x00);
      delay(3);
  digitalWrite(chipSelectPin, HIGH);

  unsigned long pre = ((presH *256) + presL)/64;
  unsigned long temp  = ((tempH *256) + tempL)/64;

  float pressure = A0_+(B1_+C12_*temp)*pre+B2_*temp;
  float baro = pressure*  (65.0/1023.0)+50.0;

  return(baro);
}

//***************************************************************

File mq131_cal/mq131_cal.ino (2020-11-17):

#define mqPin 7
#define airConvert 1
#define totalRes 1530
#define terminalRes 1000

void setup() 
{
  Serial.begin(115200); //serial baud rate
  pinMode(mqPin, INPUT); //analog input
  analogReadResolution(12); //using 12-bit ADC resolution (4096)
}
 
void loop() 
{ 
  float sensor_voltage = 0; //sensor voltage
  float rs_air = 0; //sensor resistance in air given by graph
  float r0_air = 0; //sensor resistance in air in ambient environment
  float sensor_analog = 0; //analog sensor reading
  
  //take 500 analog samples, then average them
  for(int x = 0 ; x < 500 ; x++)
  {
    sensor_analog = sensor_analog + analogRead(mqPin);
  }
  sensor_analog = sensor_analog/500.0; //take the average of analog values 
  sensor_voltage = sensor_analog*(3.3/4095.0); //converting analog value to voltage using ADC conversion 
  rs_air = (5.0*terminalRes/sensor_voltage)-totalRes; //calculate rs in air using a voltage divider
  r0_air = rs_air/airConvert; //calculate r0 in air
  
  //Serial.println(sensor_analog); //debugging for analog sensor value
  //Serial.println(sensor_voltage); //debugging for sensor voltage value
  Serial.print("R0 = ");
  Serial.println(r0_air);
  delay(500);
}

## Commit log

2020-10-20 Sensor selection excel sheet
    [GHG Emission Project Sensor Sheet.xlsx]
2020-10-25 MQ Arduino Code Commit
2020-11-17 Added KiCad and extra Excel files
    [GHG Project.kicad_pcb, GHG Project.sch, MQ Sensor Calibration Sheet.xlsx]
2020-12-21 Fixed ghg_code for simpler Matlab import
    [main_ghg_code.ino]
